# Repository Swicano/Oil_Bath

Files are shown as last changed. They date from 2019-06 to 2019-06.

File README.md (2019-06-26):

# Oil Bath Immersion Cooker

<p>
<p align="center">
    Render of the completed proect 
<p align="center"> The converted water bath with digital front panel </p>
</p>
 All the information regarding the construction and running of the "Oil Bath" built to convert an analog Thermo fisher water bath into a digital Sous Vide machine.  This project was superseded by the purchase of a commercial immersion circulator, and was repurposed to use higher temperature liquids due to the bath's metal construction and isolation of the heated area from the electronics (though it also means no circulator)

<p>
<p align="center">
    Flash Off-showing the reflected view off of the one-way mirror Flash On-showing the internal view past the one-way mirror 
<p align="center"> The conversion in place on the old bath, with electronics hidden behind a one way mirror </p>
</p>

This project started in early 2016 when immersion circulators such as Anova's were still in the $200 range, and required the additional purchase of a bath to insert them into. From my experience using them for synthesizing gold nanorods, I knew lab water baths could do the job just as well, and used lab equipment can be had for a song. The only downside was that the models showing up on Ebay were analog only but I purchased a Precision Water Bath 182 (it had precision in the name, so it must be precise) for $35 shipped anyway. Upon arrival I was surprised at the elegant minimalism of it's guts. A heating resistor, an On/Off switch, and two adjustable thermal cutoffs wired directly to the mains was the entirety of it! 

Converting it from "set-it-and-forget-it" analog knobs to "SousVide status" was simple: turn all the cutoffs temperatures to max, add a solid state relay controlled extension cord and use an arduino to drive the relay, according to some feedback from a PTD. 

It existed in this breadboarded (eventually protoboarded) state for nearly 2 years, fully functional, and seeing frequent use, but not exactly beautiful.

<p>
<p align="center">
    the brains of the operation The PTD circuit 
<p align="center"> The "good enough" conversion (not pictured: the SSR driving the bath) </p>
</p>

But I was moving soon, and my new roommates would not appreciate the half-deconstructed nature of it, so I set out to integrate the new control circuitry into the bath. I decided to do the conversion in a reversible way, and with the electronics still visible, in homage to how it had existed for 2 years of it's second life. As well, I wanted to keep the big clicky power switch, I love big clicky switches that directly cut mains power, rather than those little soft buttons that are only doing it in software.

The cleaned up bath took a few months of intermittent 3D printing and test fitting, and last minute design changes (such as switching to the Max31865 to read the RTD) to come together, but by the time it did, it was a beauty to behold. Unfortunately, in the same span, a $70 Anova Nano appeared at my house. I dont have a need for two water immersion heaters, so this old bath has been relegated to experimental duty: used to cook in salt, or incubate various yeast and lactobacilli projects, or confit.

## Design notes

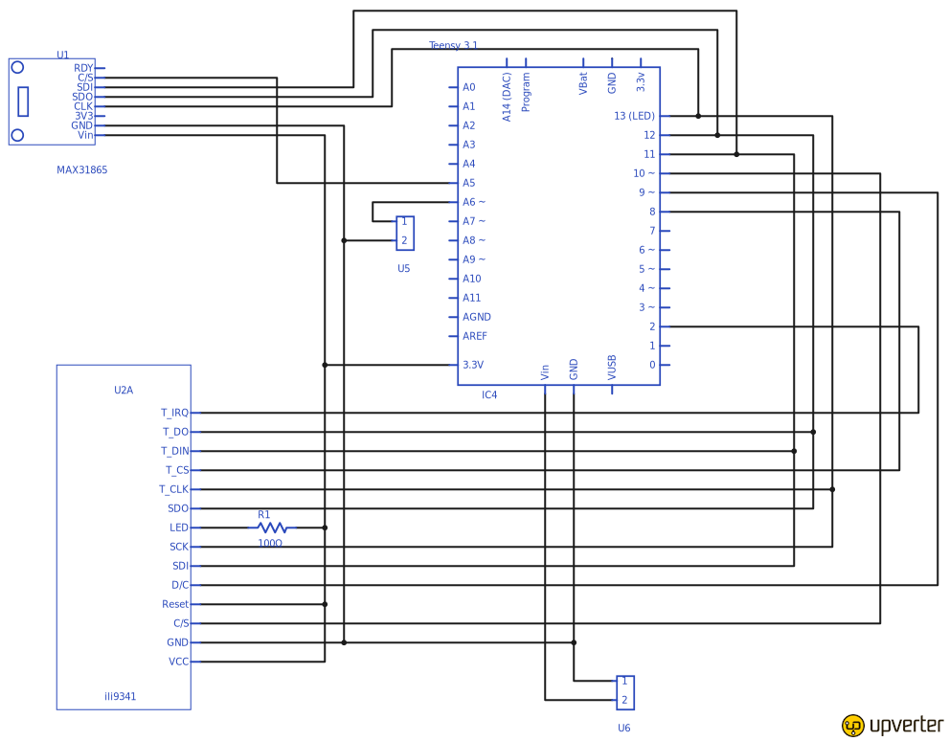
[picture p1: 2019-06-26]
PCBFiles/Oil_Bath-default.png

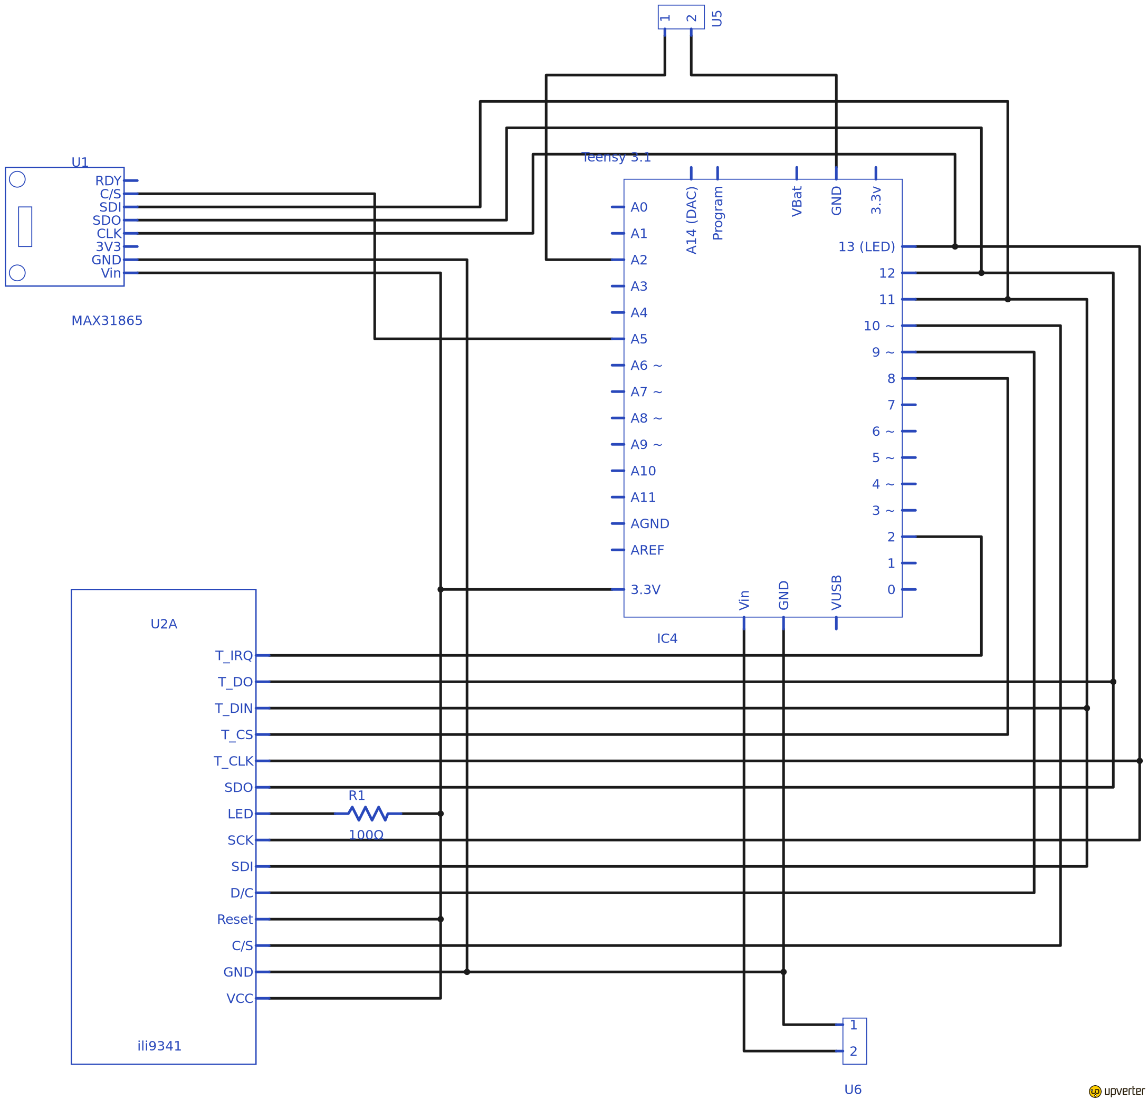
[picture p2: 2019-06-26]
PCBFiles/Oil_Bath-hd-default.png

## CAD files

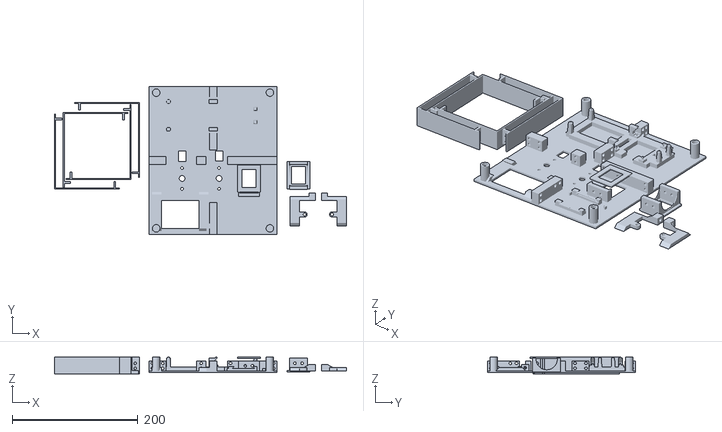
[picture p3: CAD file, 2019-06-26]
3DPrintFiles/overall v33.stl
464.8 x 234.9 x 27.0

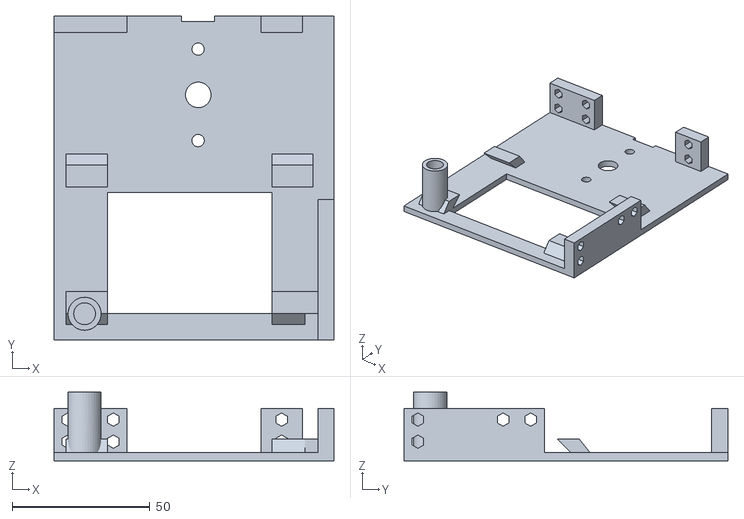
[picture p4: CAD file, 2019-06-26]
3DPrintFiles/bottomLeftV1.stl
101.6 x 117.5 x 25.0

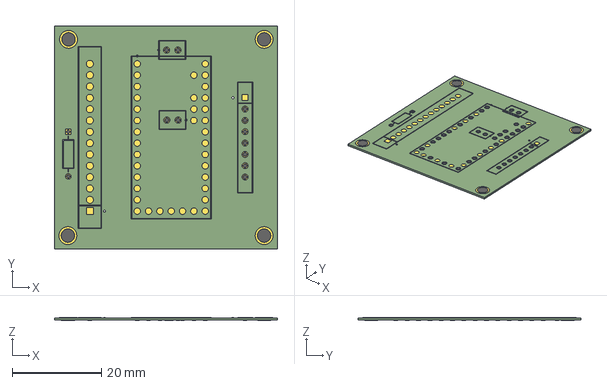
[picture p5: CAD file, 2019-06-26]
PCBFiles/Oil_Bath_step.stp
50.0 x 50.0 x 0.598 mm

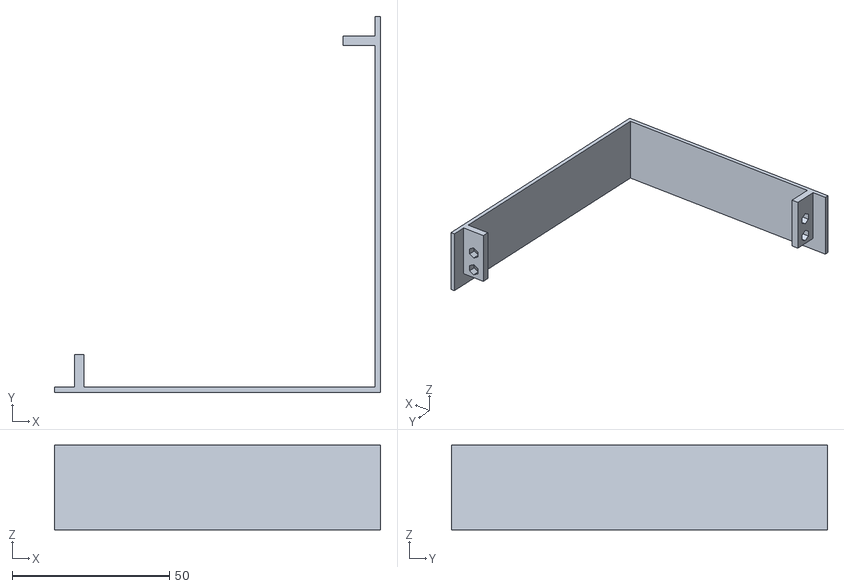
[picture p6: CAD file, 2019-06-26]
3DPrintFiles/SideBottomRightV1.stl
103.6 x 119.5 x 27.0

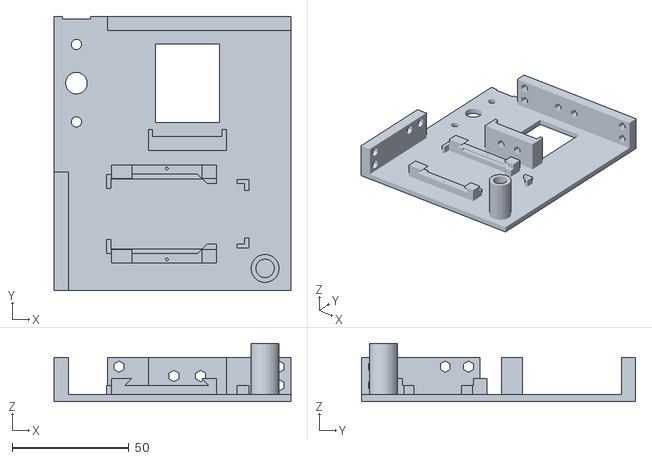
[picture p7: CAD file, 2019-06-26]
3DPrintFiles/bottomRightV1.stl
101.6 x 117.5 x 25.0

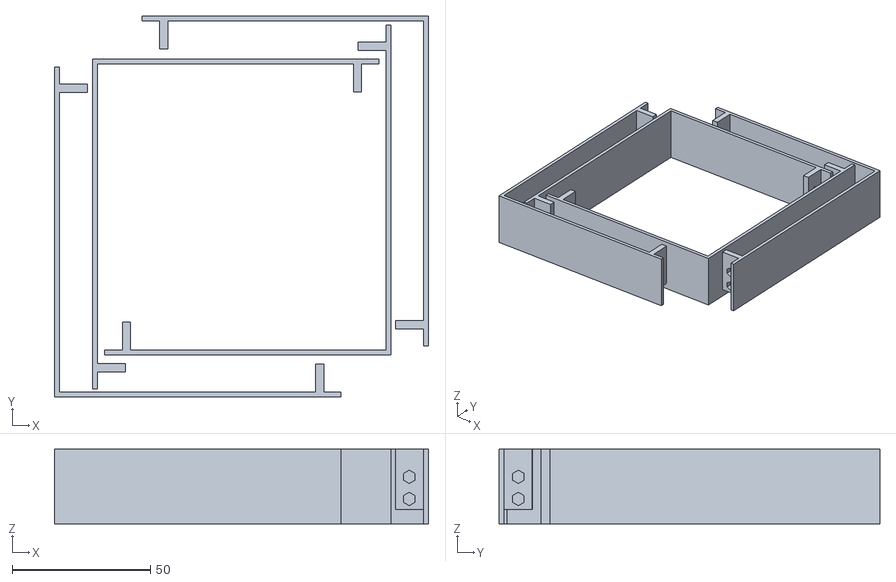
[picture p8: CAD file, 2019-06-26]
3DPrintFiles/AllSidesV1.stl
135.4 x 137.8 x 27.0

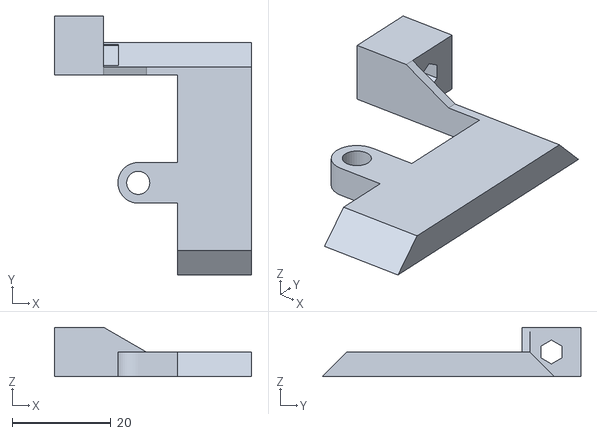
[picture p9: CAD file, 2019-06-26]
3DPrintFiles/SSRholderRightV1.stl
40.0 x 52.6 x 10.0

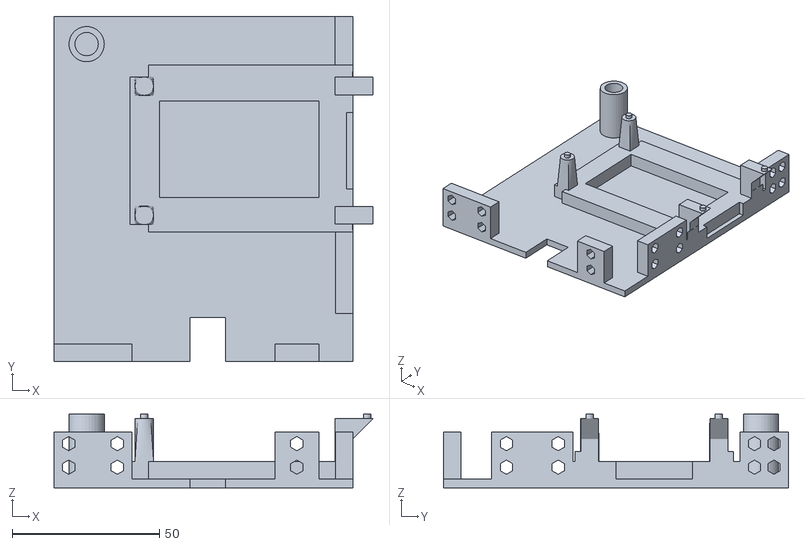
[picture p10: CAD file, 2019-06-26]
3DPrintFiles/TopLeftV1.stl
108.5 x 117.5 x 25.0

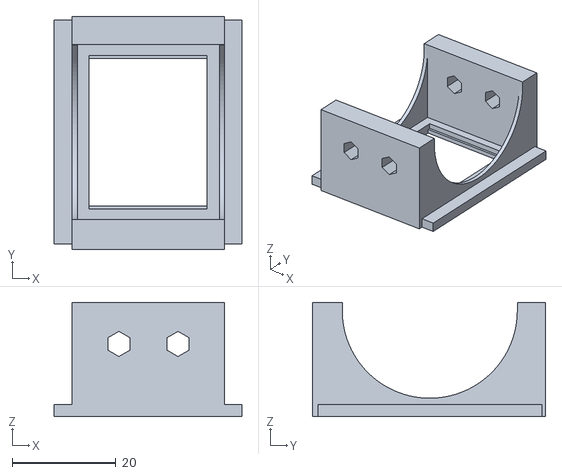
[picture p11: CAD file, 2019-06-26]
3DPrintFiles/ButtonholderV1.stl
36.2 x 44.9 x 22.0

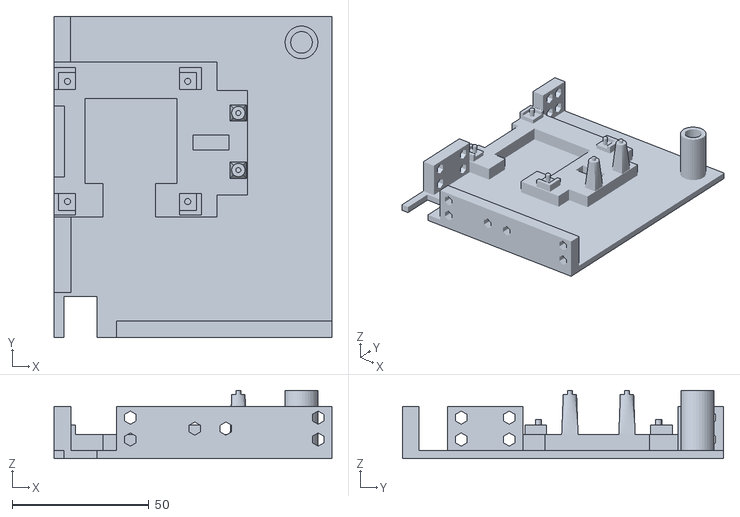
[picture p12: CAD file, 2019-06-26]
3DPrintFiles/TopRightV1.stl
101.6 x 117.5 x 25.0

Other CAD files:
3DPrintFiles/SSRholderLeftV1.stl
3DPrintFiles/SideTopRightV2.stl
3DPrintFiles/SideBottomLeftV1.stl
3DPrintFiles/SideTopLeftV1.stl
3DPrintFiles/SideTopRightV1.stl

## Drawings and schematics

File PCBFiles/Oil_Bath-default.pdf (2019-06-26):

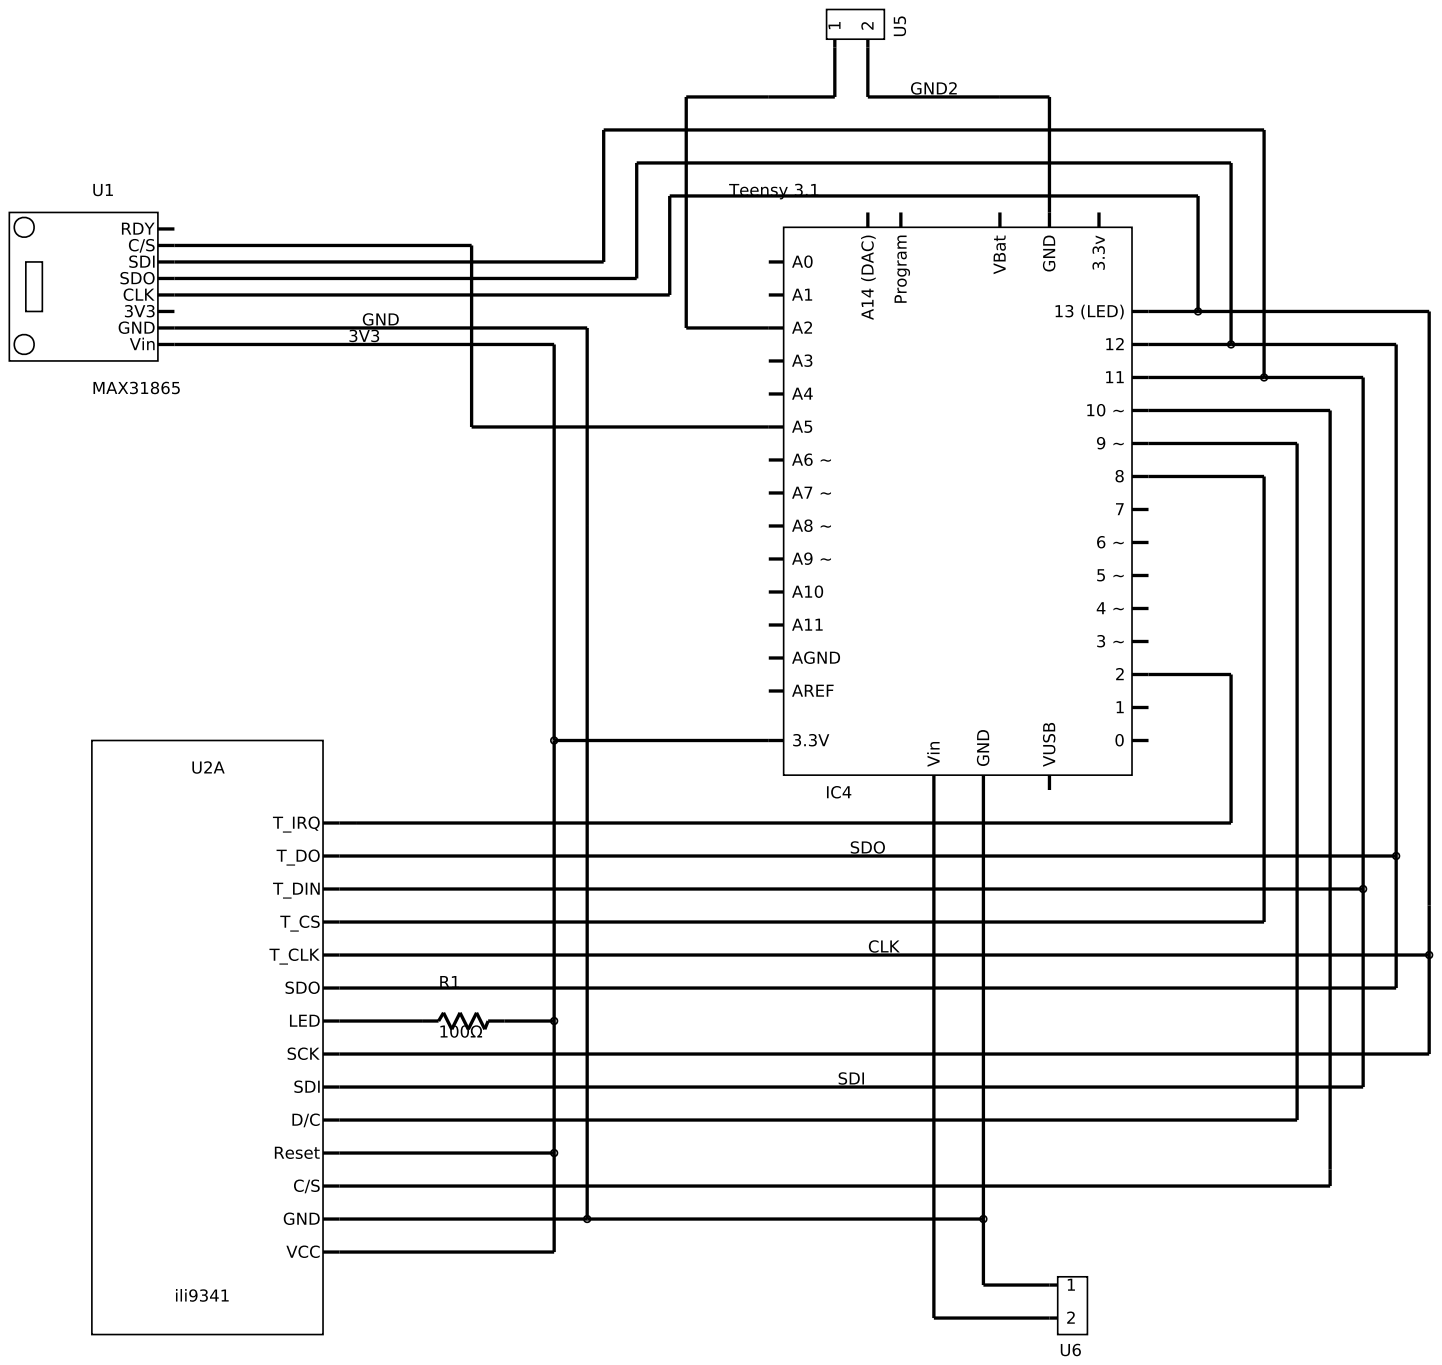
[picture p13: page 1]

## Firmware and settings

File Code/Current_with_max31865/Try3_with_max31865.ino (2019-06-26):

#include <XPT2046_Touchscreen.h>
#include <PID_v1.h>
#include <PID_AutoTune_v0.h>
#include <font_Arial.h>
#include <font_ArialBold.h>
#include <ILI9341_t3.h>
#include "SPI.h"
#include <Adafruit_MAX31865.h>

//*************************************************************************************
// screen usage variables
//*************************************************************************************
#define TFT_DC  9
#define TFT_CS 10
#define CS_PIN  8
#define TIRQ_PIN  2
XPT2046_Touchscreen ts(CS_PIN, TIRQ_PIN);  
ILI9341_t3 tft = ILI9341_t3(TFT_CS, TFT_DC);
int Y_min = 0;
int Y_max = 4096;
int X_min = 0;
int X_max = 4096; 
elapsedMillis TFTupdateTimer;
int TFTupdatePeriod = 1077;    //millis
elapsedMillis buttonmillis;                 // touchscreen debouncing
int button_timeout = 30;       //millis     // touchscreen debouncing
int totalTime = 0;

//*************************************************************************************
// PID control and temp sense variable
//*************************************************************************************
Adafruit_MAX31865 maxi = Adafruit_MAX31865(19);
#define RREF      430.0
#define RNOMINAL  100.0
elapsedMillis TempUpdateTimer;
int TempUpdatePeriod = 1013;     //millis

double Setpoint = 60.0;
double Input = 21;
double Output = 0;
// pid tuning parameters
double Kp = 10;   //proportionality terms
double Ki = 0.002; //.05   ; //1.7
double Kd = 0;
double Ks = 0; //0.5;
double Gp = 0;    // gain terms
double Gi = 0;
double Gd = 0; 
double Gs = 0;
double Err_n = 0; // "new" error term
double Err_l = 0; // previous error terms
elapsedMillis PIDUpdateTimer;
int PIDUpdatePeriod = 1053;        //millis
// 61.10, 119.83, 0.08 

int RelayPin = A6;
elapsedMillis OutputUpdateTimer;
int OutputUpdatePeriod = 1000;     //millis


elapsedMillis SerialUpdateTimer;
int SerialUpdatePeriod = 10000;     //millis

//*************************************************************************************
// screen usage Functions
//*************************************************************************************
float CtoF (float C_temp)
{return C_temp*9/5+32.0;
}

int MapX( int touch_input)
{
  int result = touch_input*320/(X_max-X_min);
  return result;
}

int MapY( int touch_input)
{
  int result = touch_input*240/(Y_max-Y_min);
  return result;
}
void drawTFT_Text()
{
  tft.setFont(Arial_24);
  tft.setCursor(0,58);
  tft.println("Current:");
  tft.setCursor(210,58);
  tft.println("Set to:");
}
void drawTFT_Buttons()
{
  
  tft.fillRoundRect(120,100,80,40,15,ILI9341_BLACK);   // middle rect
  tft.drawRoundRect(120,100,80,40,15,ILI9341_WHITE);   // middle rect

  tft.fillRoundRect(120,50,80,40,15,ILI9341_BLACK);
  tft.drawRoundRect(120,50,80,40,15,ILI9341_WHITE);    // top rect
  tft.drawLine(145,80,160,60,ILI9341_WHITE);           // top triangle
  tft.drawLine(160,60,175,80,ILI9341_WHITE);

  tft.fillRoundRect(120,150,80,40,15,ILI9341_BLACK);
  tft.drawRoundRect(120,150,80,40,15,ILI9341_WHITE);   // bottom rect
  tft.drawLine(145,160,160,180,ILI9341_WHITE);         // bottom triangle
  tft.drawLine(160,180,175,160,ILI9341_WHITE);
}
void drawTFT_Base()
{
  tft.fillScreen(ILI9341_BLACK);
  drawTFT_Buttons();
  drawTFT_Text();
}

void drawTFT_Temps(float curr, float setp)
{
  tft.fillRect(10,108,100,20, ILI9341_BLACK);
  tft.setFont(Arial_20);
  tft.setCursor(10,108);
  tft.print(curr,1);
  tft.setFont(Arial_8);
  tft.print(" o");
  tft.setFont(Arial_20);
  tft.print("C");

  tft.fillRect(10,158,100,20, ILI9341_BLACK);
  tft.setFont(Arial_20);
  tft.setCursor(10,158);
  tft.print(CtoF(curr),1);
  tft.setFont(Arial_8);
  tft.print(" o");
  tft.setFont(Arial_20);
  tft.print("F");

  tft.fillRect(210,108,100,20, ILI9341_BLACK);
  tft.setFont(Arial_20);
  tft.setCursor(210,108);
  tft.print(setp,1);
  tft.setFont(Arial_8);
  tft.print(" o");
  tft.setFont(Arial_20);
  tft.print("C");

  tft.fillRect(210,158,100,20, ILI9341_BLACK);
  tft.setFont(Arial_20);
  tft.setCursor(210,158);
  tft.print(CtoF(setp),1);
  tft.setFont(Arial_8);
  tft.print(" o");
  tft.setFont(Arial_20);
  tft.print("F");
}

//*************************************************************************************
//  PID control and temp sense Functions
//*************************************************************************************

void TempToInput(){
  uint16_t rtd = maxi.readRTD();
  Input = maxi.temperature(RNOMINAL, RREF);
}

void UpdatePID(){
  Err_n = Setpoint - Input;
  Gs = Ks*(Setpoint-25);
  Gp = min(Err_n*Kp,255);
  Gi += Err_n*Ki*PIDUpdatePeriod/1000;  
  Gi = min(Gi, 255-Gp-Gs);
  Gi = max(Gi, -255+Gp);
  Gd = (Err_n-Err_l)/(PIDUpdatePeriod/1000)*Kd;
  
  Output = (11.0/16)*Output + (5.0/16)*(Gp+Gi+Gd+Gs); // (Gp+Gi+Gd+Gs);
  Err_l = Err_n;
}

void UpdateOutput(){
  // this might become much more complicated, thats why it's its own function/loop
  // TODO: what is A6 write resolution? 255?
  analogWrite(RelayPin, min(Output, 255));
}

void UpdateSerial(){
  totalTime += SerialUpdateTimer/1000; 
  Serial.print(totalTime);
  Serial.print(",");
  Serial.print(Setpoint);
  Serial.print(",");
  Serial.print(Input);
  Serial.print(",");
  Serial.print(Err_n);
  Serial.print(",");
  Serial.print(Err_l);
  Serial.print(",");
  Serial.print(Gp);
  Serial.print(",");
  Serial.print(Gi);
  Serial.print(",");
  Serial.print(Gd);
  Serial.print(",");
  Serial.print(Gs);
  Serial.print(",");
  Serial.print(Output);
  Serial.println(", 0");
}


 //*****************************************************************************************************
 //  setup time
 //*****************************************************************************************************

void setup() {
  // setup serial stuff
  Serial.begin(115200);

  // setup temp measuring stuff
  maxi.begin(MAX31865_3WIRE);  // set to 2WIRE or 4WIRE as necessary
  
  //setup touchscreen variables*********************************//
  tft.begin();                                                  //
  ts.begin();                                                   //
  tft.setRotation(1);                                           //
  tft.fillScreen(ILI9341_BLACK);                                //
  tft.setTextColor(ILI9341_WHITE);                              //
  tft.setFont(Arial_24);                                        //
  tft.setCursor(0,0);                                           //
  tft.println("Waiting for Arduino Serial Monitor...");         //
  tft.fillRect(0,0,24,24, ILI9341_BLACK);                       //
  //************************************************************//

  //setup driving stuff
  pinMode(RelayPin, OUTPUT);                                    //
  
  //tft.println("WALUIGI WAAAAAAAA");                             //
  //if (!autotune){                                               //
  //  myPID.SetMode(AUTOMATIC);                                   //
  //}                                                             //
  //outputDriveTimer.priority(100);                               //
  //outputDriveTimer.begin(DriveOutput, 15000);                   //
  //tempMeasTimer.begin( TempToInput, 14001 );                    //
  //************************************************************//
  
  //while (!Serial | lastLogTime>8000) ; // wait for Arduino Serial Monitor
  Serial.println("ILI9341 Test!"); 

  // read diagnostics (optional but can help debug problems)
  uint8_t x = tft.readcommand8(ILI9341_RDMODE);
  Serial.print("Display Power Mode: 0x"); Serial.println(x, HEX);
  x = tft.readcommand8(ILI9341_RDMADCTL);
  Serial.print("MADCTL Mode: 0x"); Serial.println(x, HEX);
  x = tft.readcommand8(ILI9341_RDPIXFMT);
  Serial.print("Pixel Format: 0x"); Serial.println(x, HEX);
  x = tft.readcommand8(ILI9341_RDIMGFMT);
  Serial.print("Image Format: 0x"); Serial.println(x, HEX);
  x = tft.readcommand8(ILI9341_RDSELFDIAG);
  Serial.print("Self Diagnostic: 0x"); Serial.println(x, HEX); 
  Serial.print("0,");
  Serial.print("Setpoint");
  Serial.print(",");
  Serial.print("Input");
  Serial.print(",");
  Serial.print("Err_n");
  Serial.print(",");
  Serial.print("Err_l");
  Serial.print(",");
  Serial.print("Kp");
  Serial.print(",");
  Serial.print("Ki");
  Serial.print(",");
  Serial.print("Kd");
  Serial.print(",");
  Serial.print("Ks");
  Serial.print(",");
  Serial.print("Output");
  Serial.println(", 0"); 

  
  drawTFT_Base();
  drawTFT_Temps(Input,Setpoint);  
}


void loop() {

  // update the TFT
  if (TFTupdateTimer > TFTupdatePeriod){
    //drawTFT_Base();
    drawTFT_Temps(Input,Setpoint);
    TFTupdateTimer = 0;
  }

  // update the touchscreen
  if (ts.touched() && (buttonmillis>button_timeout)) {
    TS_Point p = ts.getPoint();
    float pointX = MapX(p.x);
    float pointY = MapY(p.y);
    if (pointX < 200 && pointX >120)
    {
      if(pointY <90 ){
        //top button touched
        tft.fillRoundRect(125,55,70,30,15,ILI9341_BLUE);   // top rect
        Setpoint = Setpoint+0.1; //increment setpoint
      }
      else if (pointY > 150){
        //bottom button touched
        tft.fillRoundRect(125,155,70,30,15,ILI9341_BLUE); 
        Setpoint = Setpoint-0.1; //decrement setpoint
      }
      else{
        //middlebutton
        tft.fillRoundRect(125,105,70,30,15,ILI9341_BLUE);
      }
      buttonmillis = 0;
    }
    drawTFT_Buttons();
    drawTFT_Temps(Input,Setpoint);
  }

  // update the Temp data
  if (TempUpdateTimer > TempUpdatePeriod){
    TempToInput();
    TempUpdateTimer = 0;
  }

  // Update the PID stuff
    if (PIDUpdateTimer > PIDUpdatePeriod){
    UpdatePID();
    PIDUpdateTimer = 0;
  }

  // Update the output (likely trivial)
    if (OutputUpdateTimer > OutputUpdatePeriod){
    UpdateOutput();
    OutputUpdateTimer = 0;
  }
  
  // update Serial Stuff
    if (SerialUpdateTimer > SerialUpdatePeriod){
    UpdateSerial();
    SerialUpdateTimer = 0;
  }
  
}

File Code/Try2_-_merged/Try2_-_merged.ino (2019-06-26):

#include <XPT2046_Touchscreen.h>
#include <PID_v1.h>
#include <PID_AutoTune_v0.h>
#include <font_Arial.h>
#include <font_ArialBold.h>
#include <ILI9341_t3.h>
#include "SPI.h"

//*************************************************************************************
// screen usage variables
//*************************************************************************************
int Y_min = 0;
int Y_max = 4096;
int X_min = 0;
int X_max = 4096; 
elapsedMillis screenUpdate;
elapsedMillis buttonmillis;
int button_timeout = 50; //millis
#define TFT_DC  9
#define TFT_CS 10
#define CS_PIN  8
// MOSI=11, MISO=12, SCK=13
//XPT2046_Touchscreen ts(CS_PIN);
#define TIRQ_PIN  2
//XPT2046_Touchscreen ts(CS_PIN);  // Param 2 - NULL - No interrupts
//XPT2046_Touchscreen ts(CS_PIN, 255);  // Param 2 - 255 - No interrupts
XPT2046_Touchscreen ts(CS_PIN, TIRQ_PIN);  // Param 2 - Touch IRQ Pin - interrupt enabled polling
// Use hardware SPI (on Uno, #13, #12, #11) and the above for CS/DC
ILI9341_t3 tft = ILI9341_t3(TFT_CS, TFT_DC);

//*************************************************************************************
// PID control and temp sense variable
//*************************************************************************************
IntervalTimer outputDriveTimer;
IntervalTimer tempMeasTimer;
const int logInterval = 10000; // log every 10 seconds
elapsedMillis lastLogTime;
elapsedMillis DoControltimer;
int sensorPinH = A9;
int sensorPinL = A0;
int RelayPin = A2;
double Setpoint = 82.2;
double Input;
double Output;
volatile long onTime = 0;
// pid tuning parameters
double Kp = 70;
double Ki = 17.2;
double Kd = 0;
//Specify the links and initial tuning parameters
PID myPID(&Input, &Output, &Setpoint, Kp, Ki, Kd, DIRECT);
int WindowSize = 500; 
long windowStartTime;
// ************************************************
// Auto Tune Variables and constants
// ************************************************
byte ATuneModeRemember=2;
double aTuneStep=400;
double aTuneNoise=1.5;
unsigned int aTuneLookBack=150;
// 61.10, 119.83, 0.08 
boolean tuning = false;
boolean autotune = 0;

PID_ATune aTune(&Input, &Output);


//*************************************************************************************
// screen usage Functions
//*************************************************************************************
float CtoF (float C_temp)
{
  return C_temp*9/5+32.0;
}

int MapX( int touch_input)
{
  int result = touch_input*320/(X_max-X_min);
  return result;
}

int MapY( int touch_input)
{
  int result = touch_input*240/(Y_max-Y_min);
  return result;
}
void drawText()
{
  tft.setFont(Arial_24);
  tft.setCursor(0,58);
  tft.println("Current:");

  tft.setCursor(210,58);
  tft.println("Set to:");
}
void drawButtons()
{
  
  tft.fillRoundRect(120,100,80,40,15,ILI9341_BLACK);  // middle rect
  tft.drawRoundRect(120,100,80,40,15,ILI9341_WHITE);  // middle rect

  tft.fillRoundRect(120,50,80,40,15,ILI9341_BLACK);
  tft.drawRoundRect(120,50,80,40,15,ILI9341_WHITE);   // top rect
  tft.drawLine(145,80,160,60,ILI9341_WHITE);            // top triangle
  tft.drawLine(160,60,175,80,ILI9341_WHITE);

  tft.fillRoundRect(120,150,80,40,15,ILI9341_BLACK);
  tft.drawRoundRect(120,150,80,40,15,ILI9341_WHITE);  // bottom rect
  tft.drawLine(145,160,160,180,ILI9341_WHITE);            // bottom triangle
  tft.drawLine(160,180,175,160,ILI9341_WHITE);
}
void drawBaseScreen()
{
  tft.fillScreen(ILI9341_BLACK);
  drawButtons();
  drawText();
}
void updateTemps(float curr, float setp)
{
  tft.fillRect(10,108,100,20, ILI9341_BLACK);
  tft.setFont(Arial_20);
  tft.setCursor(10,108);
  tft.print(curr,1);
  tft.setFont(Arial_8);
  tft.print(" o");
  tft.setFont(Arial_20);
  tft.print("C");

  tft.fillRect(10,158,100,20, ILI9341_BLACK);
  tft.setFont(Arial_20);
  tft.setCursor(10,158);
  tft.print(CtoF(curr),1);
  tft.setFont(Arial_8);
  tft.print(" o");
  tft.setFont(Arial_20);
  tft.print("F");

  tft.fillRect(210,108,100,20, ILI9341_BLACK);
  tft.setFont(Arial_20);
  tft.setCursor(210,108);
  tft.print(setp,1);
  tft.setFont(Arial_8);
  tft.print(" o");
  tft.setFont(Arial_20);
  tft.print("C");

  tft.fillRect(210,158,100,20, ILI9341_BLACK);
  tft.setFont(Arial_20);
  tft.setCursor(210,158);
  tft.print(CtoF(setp),1);
  tft.setFont(Arial_8);
  tft.print(" o");
  tft.setFont(Arial_20);
  tft.print("F");
}

//*************************************************************************************
//  PID control and temp sense Functions
//*************************************************************************************

void TempToInput(){
  float temp = readTemp(sensorPinH,sensorPinL);
  noInterrupts();
  Input = temp;
  interrupts();
}

void DoControl()
{
  // Read the input:
  if (tuning) // run the auto-tuner
  {
     if (aTune.Runtime()) // returns 'true' when done
     {
       tuning = false;

       // Extract the auto-tune calculated parameters
       Kp = aTune.GetKp();
       Ki = aTune.GetKi();
       Kd = aTune.GetKd();

       // Re-tune the PID and revert to normal control mode
       myPID.SetTunings(Kp,Ki,Kd);
       myPID.SetMode(ATuneModeRemember);
     }
  }
  else // Execute control algorithm
  {
     myPID.Compute();
  }
  
  // Time Proportional relay state is updated regularly via timer interrupt.
  noInterrupts();
  onTime = Output; 
  interrupts();
}

void Run()
{
  if (autotune && (abs(Input - Setpoint) < 0.5))  // Should be at steady-state
  {
    autotune = false;
    StartAutoTune();
  }
  if (DoControltimer>100){
    DoControl();  
    DoControltimer = 0;
  }
  
  // periodically log to serial port in csv format
  if (lastLogTime > logInterval)  
  {
    Serial.print("0,");
    Serial.print(Setpoint);
    Serial.print(",");
    Serial.print(Input);
    Serial.print(",");
    Serial.print(Kp);
    Serial.print(",");
    Serial.print(Ki);
    Serial.print(",");
    Serial.print(Kd);
    Serial.print(",");
    Serial.print(tuning);
    Serial.print(",");
    Serial.print(Output);
    Serial.println(", 0");
    lastLogTime = 0;
  }
}
void DriveOutput()
{  
  long now = millis();
  // Set the output
  // "on time" is proportional to the PID output
  if(now - windowStartTime>WindowSize)
  { //time to shift the Relay Window
     windowStartTime += WindowSize;
  }
  if(onTime > (now - windowStartTime))
  {
     digitalWrite(RelayPin,HIGH);
  }
  else
  {
     digitalWrite(RelayPin,LOW);
  }
}
void StartAutoTune()
{
   // REmember the mode we were in
   ATuneModeRemember = myPID.GetMode();

   // set up the auto-tune parameters
   aTune.SetControlType(0);
   aTune.SetNoiseBand(aTuneNoise);
   aTune.SetOutputStep(aTuneStep);
   aTune.SetLookbackSec((int)aTuneLookBack);
   tuning = true;
}
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

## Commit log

2019-06-26 PCB Files imported
    [Oil_Bath_step.stp]
2019-06-26 added arduino code
2019-06-26 moved relay pin
    [Oil_Bath_step.stp]
2019-06-26 Added 3D print and laser cutting files
    [AllSidesV1.stl, ButtonholderV1.stl, SSRholderLeftV1.stl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]
